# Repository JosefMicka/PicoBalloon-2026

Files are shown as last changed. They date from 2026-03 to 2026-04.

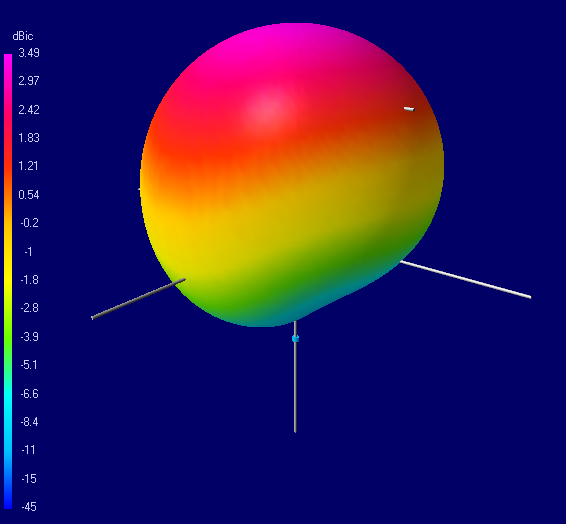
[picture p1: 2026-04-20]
Images/PicoFalcon_system_GPS1575_RHCP_Gain.PNG

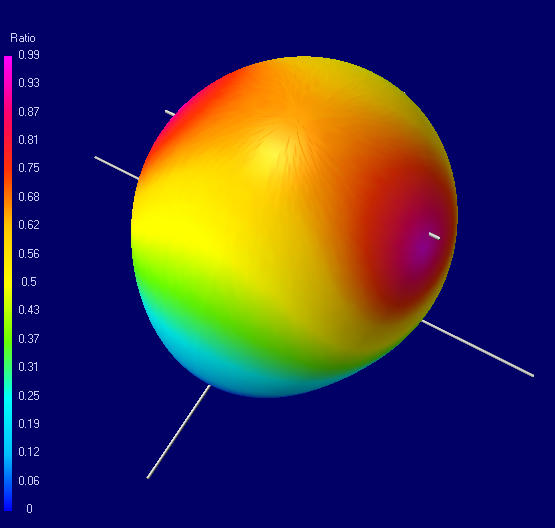
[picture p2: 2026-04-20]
Images/PicoFalcon_system_GPS1575_RHCP_AxialRatio.PNG

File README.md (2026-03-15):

# PicoBalloon-2026
The working name of this radiosonde is PicoFalcon.

This repository contains HW design with custom antenna modelling and FW for MCU.

It is based on the popular 8-bit MCU ATmega328p. The reason of choosing this MCU was simple. It was available in my household supplies.

The air-gound communication is based on LoRaWAN. It is done by radio module RFM95 which supports LoRa CSS (Chirp Spread Spectrum) modulation.

## HW
- TBD
### PCB
- TBD
### Antennas
- TBD
#### GPS antenna
- TBD
#### ISM 868 MHz antenna
- TBD

## License

This project is distributed under several licenses depending on the component:

* **Software:** All source code is licensed under the [MIT License](LICENSE).
* **Hardware:** All hardware designs (schematics, PCB layouts, 3D models) are licensed under the [CERN-OHL-P v2](https://ohwr.org/project/cernohl/wikis/Documents/CERN-OHL-version-2) or later.
* **Documentation:** All images and documentation are licensed under [CC BY 4.0](https://creativecommons.org/licenses/by/4.0/).

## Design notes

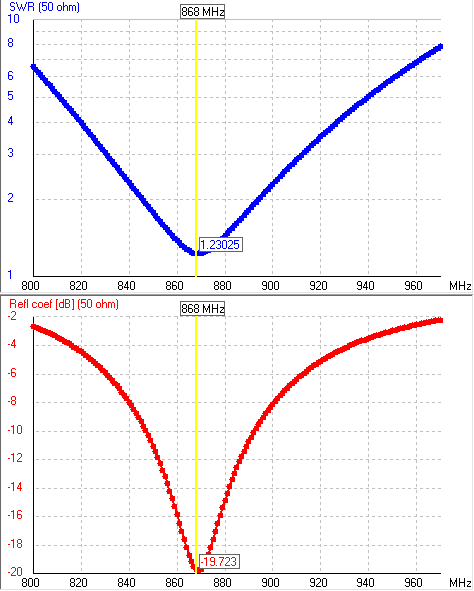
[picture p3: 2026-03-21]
Images/PicoFalcon_system_LoRa868_SWR.PNG

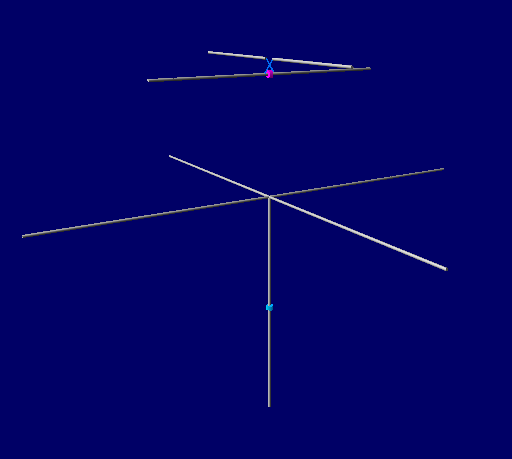
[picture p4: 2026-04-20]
Images/PicoFalcon_system_Antennas.PNG

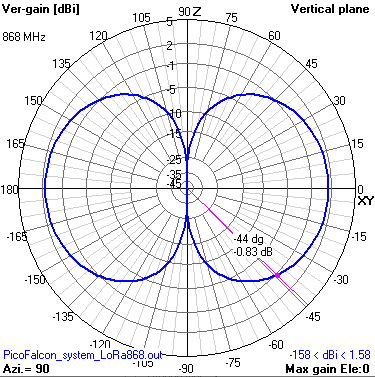
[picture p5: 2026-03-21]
Images/PicoFalcon_system_LoRa868_Vertical_Gain.PNG

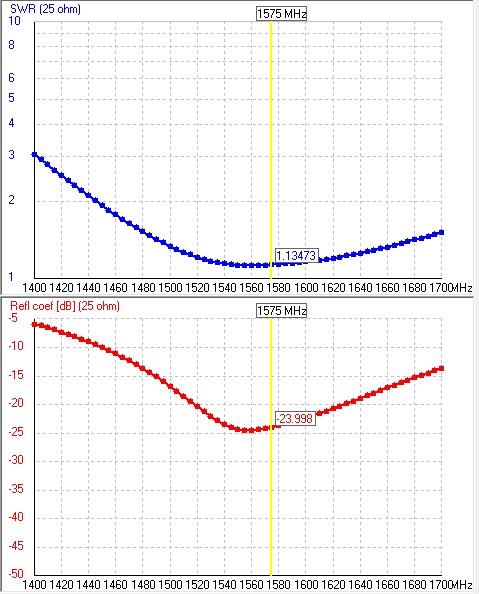
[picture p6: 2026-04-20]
Images/PicoFalcon_system_GPS1575_SWR25Ohm.PNG

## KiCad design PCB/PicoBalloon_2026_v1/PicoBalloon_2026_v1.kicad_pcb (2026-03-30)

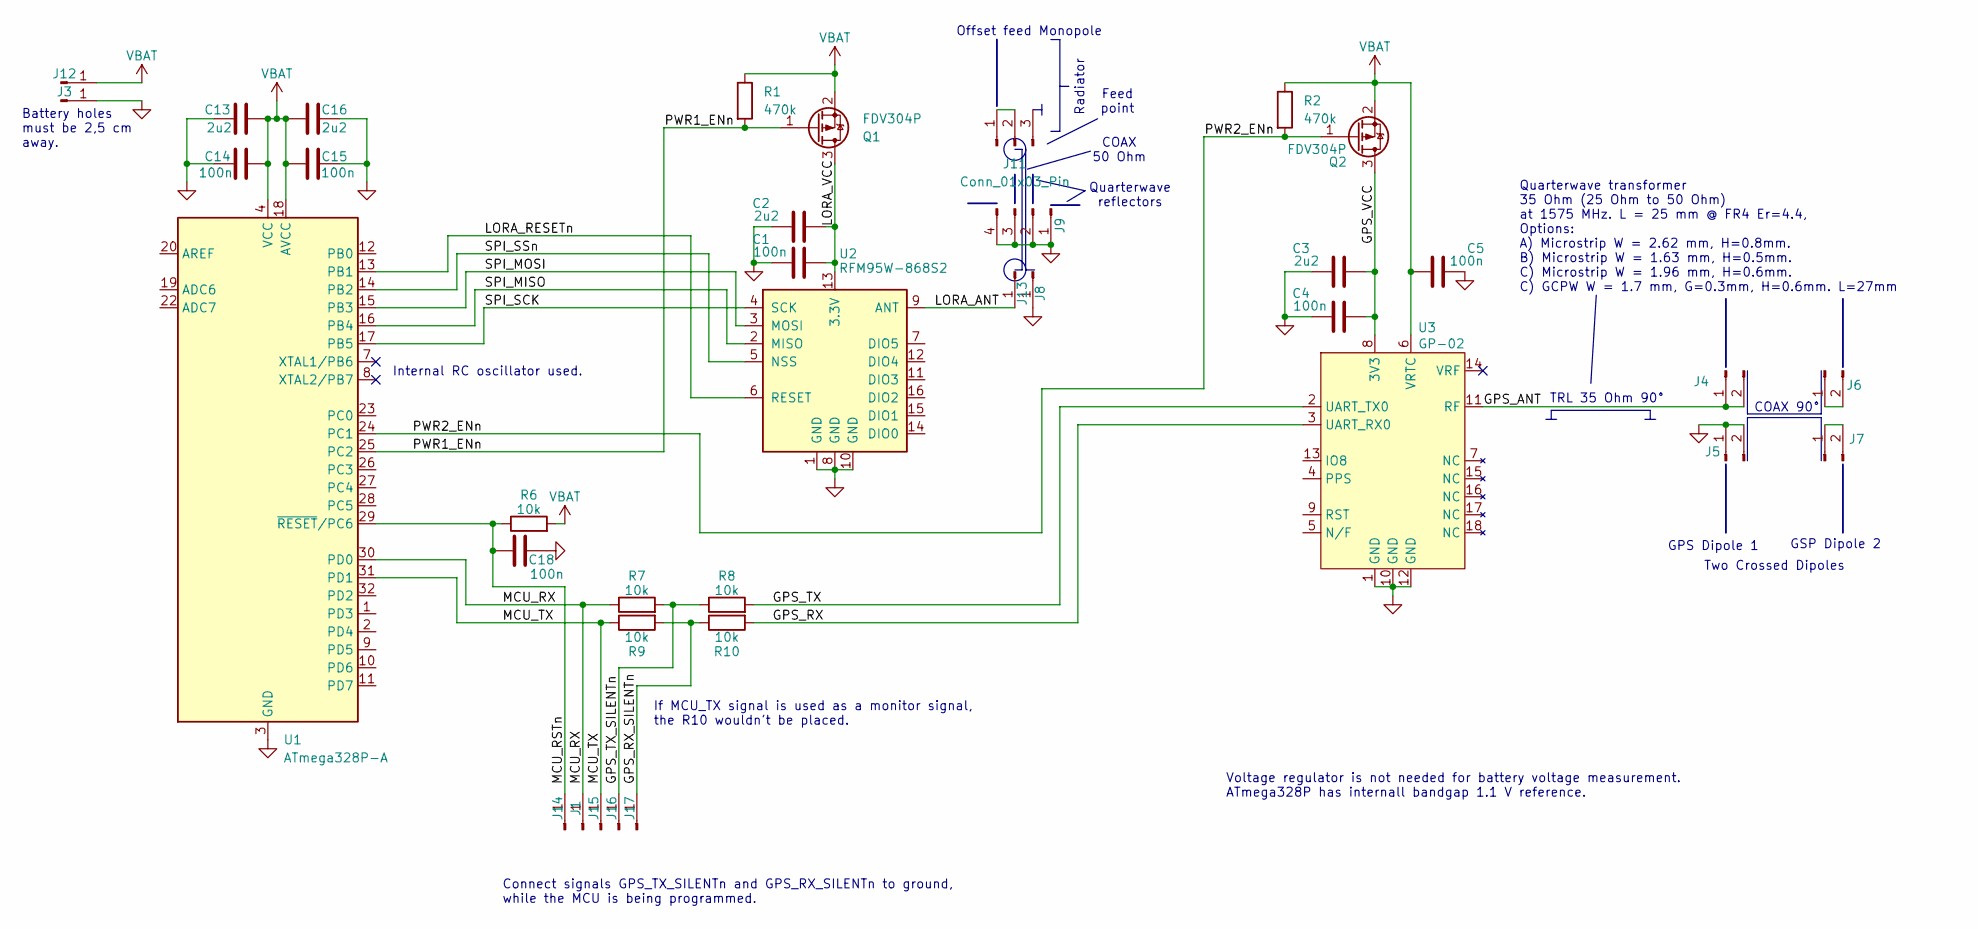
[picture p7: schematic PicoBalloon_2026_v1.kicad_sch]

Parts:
C1, C4, C5, C14, C15, C18: 100n; C_0805_2012Metric_Pad1.18x1.45mm_HandSolder
C2, C3, C13, C16: 2u2; C_0805_2012Metric_Pad1.18x1.45mm_HandSolder
J1, J14, J15, J16, J17: Conn_01x01_Pin; SolderWirePad_1x01_SMD_1x2mm
J3, J12: Conn_01x01_Pin; PinHeader_1x01_P2.54mm_Vertical
J4, J5, J6, J7: Conn_01x02_Pin; PinHeader_1x02_P1.27mm_Vertical
J8, J13: Conn_01x01_Pin; PinHeader_1x01_P1.27mm_Vertical
J9: Conn_01x04_Pin; PinHeader_1x04_P1.27mm_Vertical
J11: Conn_01x03_Pin; PinHeader_1x03_P1.27mm_Vertical
Q1, Q2: FDV304P; SOT-23
R1, R2: 470k; R_0805_2012Metric_Pad1.20x1.40mm_HandSolder
R6, R7, R8, R9, R10: 10k; R_0805_2012Metric_Pad1.20x1.40mm_HandSolder
U1: ATmega328P-A; TQFP-32_7x7mm_P0.8mm
U2: RFM95W-868S2; HOPERF_RFM9XW_SMD
U3: GP-02

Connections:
/GPS_ANT: J4.1, J4.2, U3.11 (RF)
/GPS_RX: R10.2, U3.3 (UART_RX0)
/GPS_RX_SILENTn: J17.1, R9.2, R10.1
/GPS_TX: R8.2, U3.2 (UART_TX0)
/GPS_TX_SILENTn: J16.1, R7.2, R8.1
/GPS_VCC: C3.2, C4.2, Q2.3 (D), U3.8 (3V3)
/LORA_ANT: J13.1, U2.9 (ANT)
/LORA_RESETn: U1.13 (PB1), U2.6 (RESET)
/LORA_VCC: C1.2, C2.2, Q1.3 (D), U2.13 (3.3V)
/MCU_RSTn: C18.2, J14.1, R6.1, U1.29 (~RESET/PC6)
/MCU_RX: J1.1, R7.1, U1.30 (PD0)
/MCU_TX: J15.1, R9.1, U1.31 (PD1)
/PWR1_ENn: Q1.1 (G), R1.2, U1.25 (PC2)
/PWR2_ENn: Q2.1 (G), R2.2, U1.24 (PC1)
/SPI_MISO: U1.16 (PB4), U2.2 (MISO)
/SPI_MOSI: U1.15 (PB3), U2.3 (MOSI)
/SPI_SCK: U1.17 (PB5), U2.4 (SCK)
/SPI_SSn: U1.14 (PB2), U2.5 (NSS)
GND: C1.1, C2.1, C3.1, C4.1, C5.1, C13.1, C14.1, C15.1, C16.1, C18.1, J3.1, J5.1, J5.2, J8.1, J9.1, J9.2, J9.3, J9.4, U1.3 (GND), U1.5 (GND), U1.21 (GND), U2.1 (GND), U2.8 (GND), U2.10 (GND), U3.1 (GND), U3.10 (GND), U3.12 (GND)
unnamed: J6.1, J6.2
unnamed: J7.1, J7.2
unnamed: J11.1, J11.2
VBAT: C5.2, C13.2, C14.2, C15.2, C16.2, J12.1, Q1.2 (S), Q2.2 (S), R1.1, R2.1, R6.2, U1.4 (VCC), U1.6 (VCC), U1.18 (AVCC), U3.6 (VRTC)

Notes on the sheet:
Connect signals GPS_TX_SILENTn and GPS_RX_SILENTn to ground, while the MCU is being programmed.
Quarterwave transformer 35 Ohm (25 Ohm to 50 Ohm) at 1575 MHz. L = 25 mm @ FR4 Er=4.4, Options: A) Microstrip W = 2.62 mm, H=0.8mm. B) Microstrip W = 1.63 mm, H=0.5mm. C) Microstrip W = 1.96 mm, H=0.6mm. C) GCPW W = 1.7 mm, G=0.3mm, H=0.6mm. L=27mm
Offset feed Monopole
COAX 50 Ohm
Quarterwave reflectors
TRL 35 Ohm 90°
Battery holes must be 2,5 cm away.
If MCU_TX signal is used as a monitor signal, the R10 wouldn't be placed.
COAX 90°
Two Crossed Dipoles
Internal RC oscillator used.
Feed point
GSP Dipole 2
Radiator
Voltage regulator is not needed for battery voltage measurement. ATmega328P has internall bandgap 1.1 V reference.
GPS Dipole 1

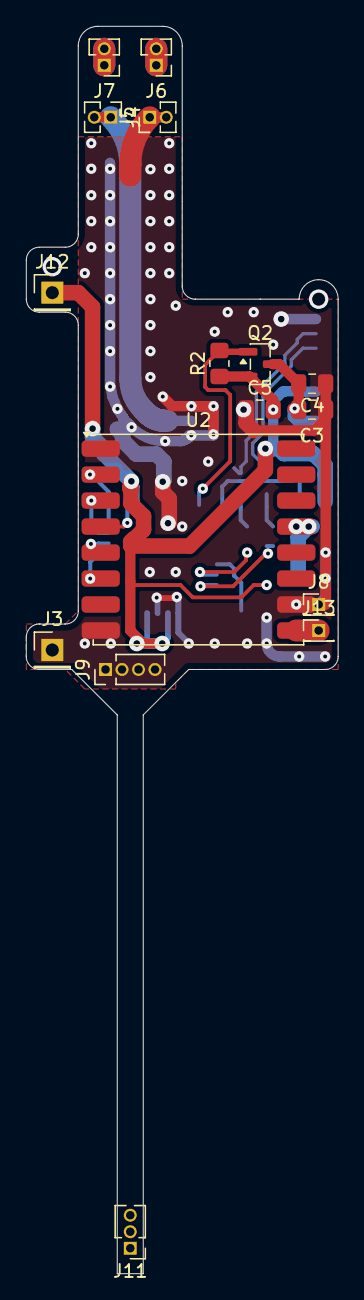
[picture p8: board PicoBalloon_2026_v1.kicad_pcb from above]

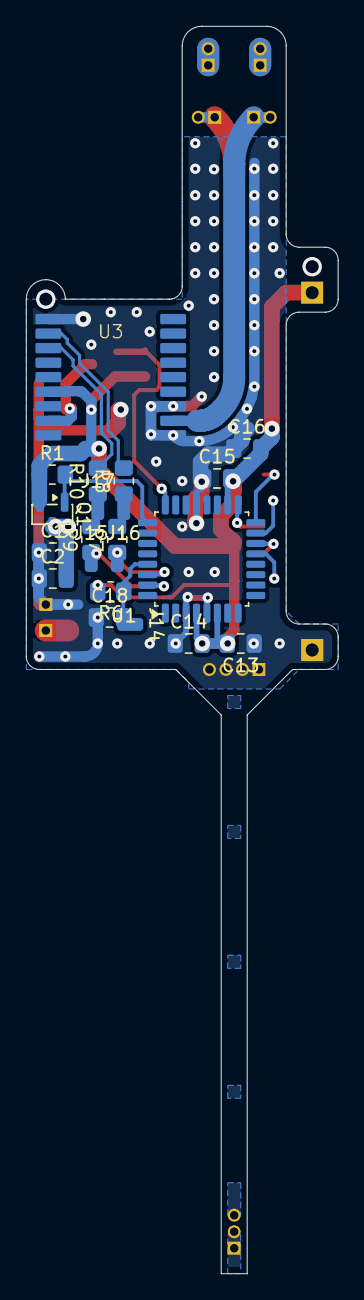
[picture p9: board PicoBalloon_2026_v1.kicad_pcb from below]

Board: 2 copper layers, 24.0 x 96.0 mm, 37 parts (21 on the bottom side), 23 nets.

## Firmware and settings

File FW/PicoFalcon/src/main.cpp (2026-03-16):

#include <Arduino.h>
#include <SoftwareSerial.h>
#include <TinyGPS++.h>

#define GPS_ON_PIN_n 13

#define GPS_RX_PIN 8
#define GPS_TX_PIN 9

SoftwareSerial gpsSerial(GPS_RX_PIN, GPS_TX_PIN);

TinyGPSPlus gps;

uint32_t time0 = 0;
bool gpsRunning = false;

void setup() {
    pinMode(GPS_ON_PIN_n, OUTPUT);
    
    if (gpsRunning) {
        digitalWrite(GPS_ON_PIN_n, LOW); // GPS on
    } else {
        digitalWrite(GPS_ON_PIN_n, HIGH); // GPS off
    }

    Serial.begin(9600);
    gpsSerial.begin(9600);
    Serial.println("Hello, GPS!");
}

void loop() {

    if (millis() - time0 > 10000) {
        time0 = millis();
        if (gpsRunning) {
            Serial.println("Turning GPS off...");
            digitalWrite(GPS_ON_PIN_n, HIGH);
            gpsRunning = false;
        } else {
            Serial.println("Turning GPS on...");
            digitalWrite(GPS_ON_PIN_n, LOW);
            gpsRunning = true;
        }
    }

    if (gpsSerial.available()) {
        if (gps.encode(gpsSerial.read())){
            if (gps.location.isValid()) {
                Serial.print("Time (UTC): ");
                Serial.print(gps.time.hour());
                Serial.print(":");
                Serial.print(gps.time.minute());
                Serial.print(" - ");

                Serial.print(gps.satellites.value());
                Serial.print(" - ");

                Serial.print("Latitude: ");
                Serial.print(gps.location.lat(), 6);
                Serial.print(" | Longitude: "); 
                Serial.print(gps.location.lng(), 6);
                Serial.print(" | Altitude: ");
                Serial.println(gps.altitude.meters());
            }
        }
    }
}

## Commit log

2026-03-16 [FW|PCB|DOCS] Initial commit.
    [PicoBalloon_2026_v1.kicad_pcb, PicoBalloon_2026_v1.kicad_sch]
2026-03-19 [ANT] LoRa 868 MHz optimized monopole antenna - 4NEC2 design.
2026-03-19 [ANT] GPS crossed dipoles antenna created. Slightly optimized.
2026-03-21 [ANT] Both antennas in system optimized.
2026-03-22 [ANT] Added image of the antenna system.
2026-03-23 [DOCS] TS5205 voltage regulator datasheet.
2026-03-23 [PCB] Schematic update. LoRa power on, GPS power on, VBAT meas. power on.
    [PicoBalloon_2026_v1.kicad_sch]
2026-03-25 [PCB] Schematic in progres.
    [PicoBalloon_2026_v1.kicad_sch]
2026-03-26 [PCB] Schematic drawing update.
    [PicoBalloon_2026_v1.kicad_sch]
2026-03-26 [PCB] Antennas drawings added to schematic.
    [PicoBalloon_2026_v1.kicad_sch]
2026-03-26 [PCB] PCB design begin.
    [PicoBalloon_2026_v1.kicad_pcb, PicoBalloon_2026_v1.kicad_sch]
2026-03-29 [PCB] PCB finished! (I hope). Not so critical signals removed. Voltage regulator removed because it is not needed.
    [PicoBalloon_2026_v1.kicad_pcb, PicoBalloon_2026_v1.kicad_sch]
2026-03-30 [PCB] Finished.
    [PicoBalloon_2026_v1-B_Cu.gbl, PicoBalloon_2026_v1-B_Mask.gbs, PicoBalloon_2026_v1-B_Paste.gbp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]
2026-03-31 [Sim] GPS antena impedance transformator.
    [25_to_50Ohm_transformation.sch]
2026-04-20 [ANT] 4NEC2 simulation updated according to designed antenna distance.
